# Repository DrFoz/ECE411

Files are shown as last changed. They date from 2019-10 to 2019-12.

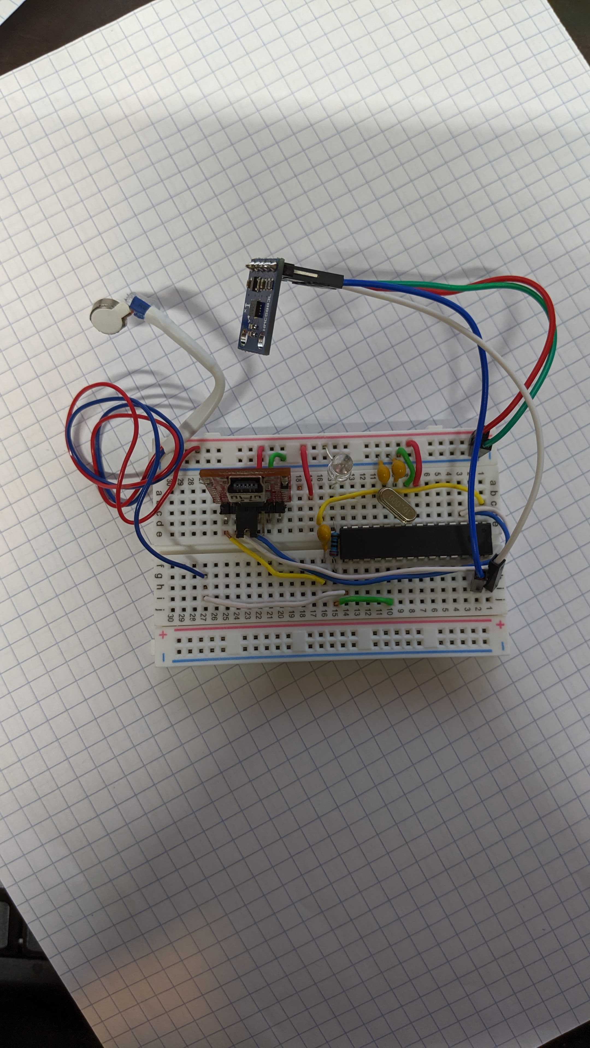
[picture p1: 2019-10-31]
IMG_20191020_224753.jpg

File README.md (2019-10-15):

# ECE411
Repository for ECE 411 practicum project documentation

Project overview

This project encompasses the hardware and software design of a haptic feedback compass
to assist an individual with landbased navigation.
Applications could include hiking, hunting, or as additional aid for the visually impaired.
Direction will be determined with the use of a digital magnometer and microprocessor. 
Mode Select and direction select will be set with the use of a momentary switch mounted to 
the case. Feedback will be generated using micro dc vibrator motor, to indicate mode and
direction selected, as well as to indicate a deviation from desired direction. During 
operation Haptic feedback intensity will be preportional to the deviation of desired 
direction of travel. Device will be powered by a lithium polymer pouch cell that is 
removable and rechargeable via external charger.

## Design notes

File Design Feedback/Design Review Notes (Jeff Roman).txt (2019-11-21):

- Board needs to have bypass capacitors on Vcc and likely on the 5V Regulator.
- Round out some of the PCB traces into a 'Knee-like' roundout.
- Via 'Fencing' or Via's close to important grounded areas.

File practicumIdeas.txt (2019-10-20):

Practicum project concepts

1. Self driving doorstop

	This design would would use infrared line tracking sensors, and user placed paths to guide a wheeled doorstop to the optimum location for door stoppage. The operation can be activated using an IR remote, or be set to auto-mode where it will secure the nearest door it can find. The actuator for the wheels will be done using a stepper motor to prevent slippage when the doorstop is in the resting state. An Atmega328P will be used with the addition of a A4988 stepper motor driver.

2. Battery Voltage tester

	This project would use a voltage sensor to test 1.5V and 9V batteries. Sensor readings would be processed using an Atmega328P microprocessor and the output(actuator) would be an oled display with the raw voltage reading and 8 led strip that would act as a bad/good gauge feedback to the user.

3.Haptic feedback compass

	This project will use a digital magnometer and an Atmega328P microprocessor to determine the direction the device is oriented. It will be worn by the user on a lanyard around there neck. Mode Select and Direction select will be set with the use of a momentary switch mounted to the case. Feedback will be generated using micro dc vibrator motor, to indicate mode and direction selected, as well as to indicate a deviation from desired direction. During operation Haptic feedback intensity will be preportional to the deviation of desired direction of travel. This can be used to assist an individual with landbased navigation. Applications could include hiking, hunting, or as additional aid for the visually impaired. 
	
We have chosen to work on the Haptic feedback compass for our practicum project.

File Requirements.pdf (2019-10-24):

# HAPTIC FEEDBACK COMPASS

## REQUIREMENTS

TYSON FOSDICK

TODD TOWNSEND

RUBEN MALDONADO

MATT SCHROEDER

Project Requirements Date: 10/15/2019

Version Number: 1.0

ECE 411

Department of Electrical and Computer Engineering

## Project Summary

This project encompasses the hardware and software design of a haptic feedback compass to assist an individual with land-based navigation. Direction will be determined with the use of a digital magnetometer and microprocessor. During operation Haptic feedback intensity will be proportional to the deviation of the end users desired direction of travel. Depending on the customer and desired application our design will accommodate multiple users creating a diverse clientele encompassing the wide range of applications.

Background
Original concept was a design for a haptic feedback dog collar to help visual impaired dogs with obstacle avoidance. This design had extreme challenges due to the unpredictable nature of the animals movement. The concept for the compass was derived from the collar project as a simplified version of the feedback device, to gain real-world tests of the components that may lead to a solution to the collar project challenges. During the product concept phase, the alternate use for the visually impaired was added to the design, as well as the concept of a web based application of the device.

## Market Analysis

The product is targeted towards hunters, hikers, and general outdoors enthusiast primarily. Alternate application for the visually impaired will be implemented after thorough real-world testing and customer feedback has been acquired, and safety and feasibility have been assessed.

There are no comparable products currently commercially available, although there are a few open source projects in the maker community that are similar in build but differ in functionality. The closest our team could find was a visual display digital compass with price ranging from ~$12-$30. Analog compass price range from ~$8-$100.

The product will be introduced at a $80 price point mainly to get a quicker market share, and get useful customer analytics for future product releases. The price will be increased with future upgraded models.

## Design Requirements

Design was created adhering to the following requirements:

Musts

Functionality

1. Acquired heading accurately reported to user
2. Operate on battery for a minimum of 4 hours

Performance

1. Give accurate feedback within a 5° plus or minus deviation
2. Low power consumption ~300mW

Economic

1. User interface equipped with user friendly options, reported from users
2. Navigation need fulfilled, reported from users
3. Priced within the market range for similar products or combination of products to equal functionality

Shoulds

Functionality

1. Run on battery for 8 hours

Performance

1. Have a rugged damage resistant enclosure
2. Be waterproof, cold resistant and heat resistant
3. Operate with extremely low power consumption ~160mW

Economic

1. Comfortable to wear, reported from users
2. Look attractive, reported from users
3. Cost no more than the cost of a commercially available digital/analog compass.

Architecture Overview:

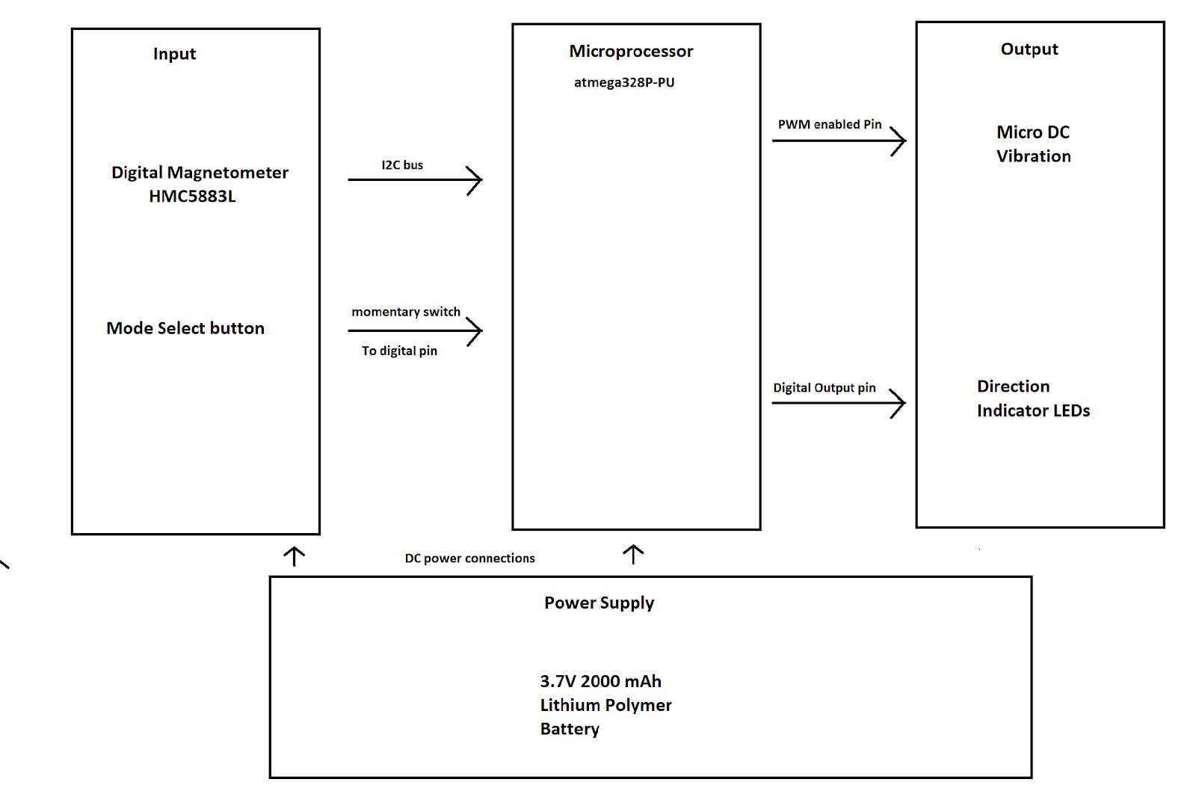
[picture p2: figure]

## Specifications:

- Processor - Atmega328P-PU with Arduino bootloader Version 3.0
- Sensor - magnetometer - P/N HMC5883L
- Actuator - Micro DC vibration motor 3v 85mA
- Power Source - 3.7v 2000mAh Lithium Polymer pouch cell
- Programming environment - Arduino IDE/Visual Studio Code
- PCB schematics - Eagle CAD
- Enclosure - Printed ABS plastic

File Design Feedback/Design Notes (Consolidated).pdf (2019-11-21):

# Design Notes (Consolidated)

## Team 6: Matthew Schroeder Todd Townsend Tyson Fosdick Ruben Maldonado

Date of review: 11/20/2019

Design reviewed by individuals from two teams: Jeff Roman
Thomas Harris

Board Layout
- Silk screen overlap throughout board.
- Silk screen is off the board in top left corner.
- Chunk of trace in DRC.
- Team name and date needs to be on board.
- Ground stitching vias are not present.
- ERC Warnings (Components that don’t need values).
- Ext. connectors and LEDs.
- Traces might need to be rounded out.
- Via ‘fencing’ or putting via’s close to important grounds may be advantageous

Schematic
- Pin 22 not grounded.
- AVCC and AREF are floating.
- User-Button not a very meaningful name.
- Labeling is done very well.
- Bypass capacitors lacking on VCC and likely 5V regulator.

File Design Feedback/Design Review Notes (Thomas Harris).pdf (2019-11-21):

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
Design notes

Board Layout
silk screen overlap throughout board
silk screen is off of the board in top left corner
chunk of trace in DRC (just a warning, wonʼt break anything)
team name and date needs to be on board
ground stitching vias are not present
you guys have a bunch of ERC warnings (components that donʼt need values, such as external connectors and LEDs, need an inherent value associated) (just a warning, wonʼt break anything)

Schematic
pin 22 is not grounded
AVCC and AREF are floating, double check that this is okay. (it should probably have a pullup or pulldown cap)
specify function of “user-button” not the most meaningful name
labeling is very well done

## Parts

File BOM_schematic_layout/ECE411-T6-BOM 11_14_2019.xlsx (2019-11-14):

Qty / Board | Qty - Total | Manufacturer Number | Manufacturer | Reference Designation | Description | SMD/Through-Hole | Price - Component | Price/Board | Price - Total | External Link:
2 | 8 | 10129379-905001BLF | Amphenol FCI (https://www.mouser.com/manufacturer/fci/) | JP1, JP2 | Header | Through-Hole | $0.26 | $0.52 | $2.08
2 | 8 | 503562 | Adafruit Industries LLC (https://www.digikey.com/en/supplier-centers/a/adafruit) | BATT | 3.7V Lipo Battery | N/A | $9.95 | $19.90 | $79.60 | https://www.adafruit.com/product/258
2 | 8 | S2B-PH-K-S(LF)(SN) | JST Sales America Inc. (https://www.digikey.com/en/supplier-centers/j/jst) | 3.7V-LIPO-1, 3.7V-LIPO-2 | JST-PH2 Connectors | Through-Hole | $0.17 | $0.34 | $1.36 | https://www.newegg.com/p/2A7-00D0-00060?item=9SIAAZM4G87031&nm_mc=knc-googlemkp-pc&gclsrc=aw.ds
1 | 4 | GY-273 HMC5883L | Honeywell (HMC5883L) | GY-273 HMC5883L | Magnetic Sensor | Through-Hole | $4.88 | $4.88 | $19.52
7 | 28 | RCS08050000Z0EA | Vishay Dale (https://www.digikey.com/en/supplier-centers/v/vishay-dale) | R4-10 | 0 Ohm Resistor | SMD | $0.17 | $1.19 | $4.76
1 | 4 | CRCW08051K50FKEAC | Vishay Dale (https://www.digikey.com/en/supplier-centers/v/vishay-dale) | R13 | 1.5 kOhm Resistor | SMD | $0.10 | $0.10 | $0.40
1 | 4 | CRCW08055K00FKTA | Vishay Dale (https://www.digikey.com/en/supplier-centers/v/vishay-dale) | R2 | 5 kOhm Resistor | SMD | $0.15 | $0.15 | $0.60
3 | 12 | CRCW0805100KJNEAC | Vishay Dale (https://www.digikey.com/en/supplier-centers/v/vishay-dale) | R1, R11, R12 | 100 kOhm Resistor | SMD | $0.10 | $0.30 | $1.20
1 | 4 | CRCW08051M00FKEAC | Vishay Dale (https://www.digikey.com/en/supplier-centers/v/vishay-dale) | R3 | 1 MOhm Resistor | SMD | $0.10 | $0.10 | $0.40
1 | 4 | C0805C222K2RECAUTO | KEMET (https://www.mouser.in/manufacturer/kemet-electronics/) | C1 | 2200pF Capacitor | SMD | $0.27 | $0.27 | $1.08
1 | 4 | TMCP1D224MTRF | Vishay / Sprague (https://www.mouser.in/manufacturer/sprague/) | C5 | 0.22uF Capacitor | SMD | $0.46 | $0.46 | $1.84
2 | 8 | 500R15N220JV4T | Johanson Dielectrics (https://www.mouser.in/manufacturer/johanson-dielectrics/) | C2, C3 | 22pF Capacitor | SMD | $0.15 | $0.30 | $1.20
1 | 4 | C0805C101J5HACAUTO | KEMET (https://www.mouser.in/manufacturer/kemet-electronics/) | C4 | 100pF Capacitor | SMD | $0.16 | $0.16 | $0.64
4 | 16 | PBHV8115TLHR | Nexperia (https://www.mouser.in/manufacturer/nexperia/) | Q1-4 | NPN Transistor | SMD | $0.39 | $1.56 | $6.24
1 | 4 | L101011MS02Q | C&K (https://www.mouser.in/manufacturer/ck-switches/) | SPST-SLIDE-SWITCH | Slideswitch | Through-Hole | $1.97 | $1.97 | $7.88
1 | 4 | TC33X-2-504G | Bourns (https://www.mouser.in/manufacturer/bourns/) | VR1 | 500 kOhm Potentiometer | SMD | $0.26 | $0.26 | $1.04
1 | 4 | ECS-160-8-30Q-VY-TR | ECS (https://www.mouser.in/manufacturer/ecs/) | Y1 | 16 MHz Oscillator | SMD | $0.72 | $0.72 | $2.88
4 | 16 | HLMP-6820 | Broadcom / Avago (https://www.mouser.in/manufacturer/broadcom/) | LED-N, LED-S, LED-E, LED-W | 5V 3.5mA Green LEDs | Through-Hole | $0.90 | $3.60 | $14.40
2 | 8 | BAS21GWX | Nexperia (https://www.mouser.in/manufacturer/nexperia/) | D1, D2 | Diode | SMD | $0.17 | $0.34 | $1.36
1 | 4 | MMSZ4684T1G | ON Semiconductor (https://www.mouser.in/manufacturer/on-semiconductor/) | Z1 | Zener Diode | SMD | $0.20 | $0.20 | $0.80
1 | 4 | SN74LVC1G14DBVR | Texas Instruments (https://www.mouser.in/manufacturer/texas-instruments/) | IC1 | Shottky Inverter | SMD | $0.33 | $0.33 | $1.32
1 | 4 | ATMEGA328P-PU | Microchip Technology / Atmel (https://www.mouser.in/manufacturer/atmel/) | U1 | Microprocessor | Through-Hole | $2.14 | $2.14 | $8.56
1 | 4 | 1241.1072 | Schurter (https://www.mouser.com/manufacturer/schurter/) | BUTTON | Flush OFF - (ON) Button | Through-Hole | $3.01 | $3.01 | $12.04
 |  |  |  |  |  |  | Total: | $42.80 | $171.20
 |  |  |  |  | SMD/Through-Hole Percentages
 |  |  |  |  | Through-Hole Types: | 7
 |  |  |  |  | Through-Hole Components: | 12
 |  |  |  |  | SMD Types: | 15
 |  |  |  |  | SMD Components: | 28
 |  |  |  |  | SMD Percentage: | 70

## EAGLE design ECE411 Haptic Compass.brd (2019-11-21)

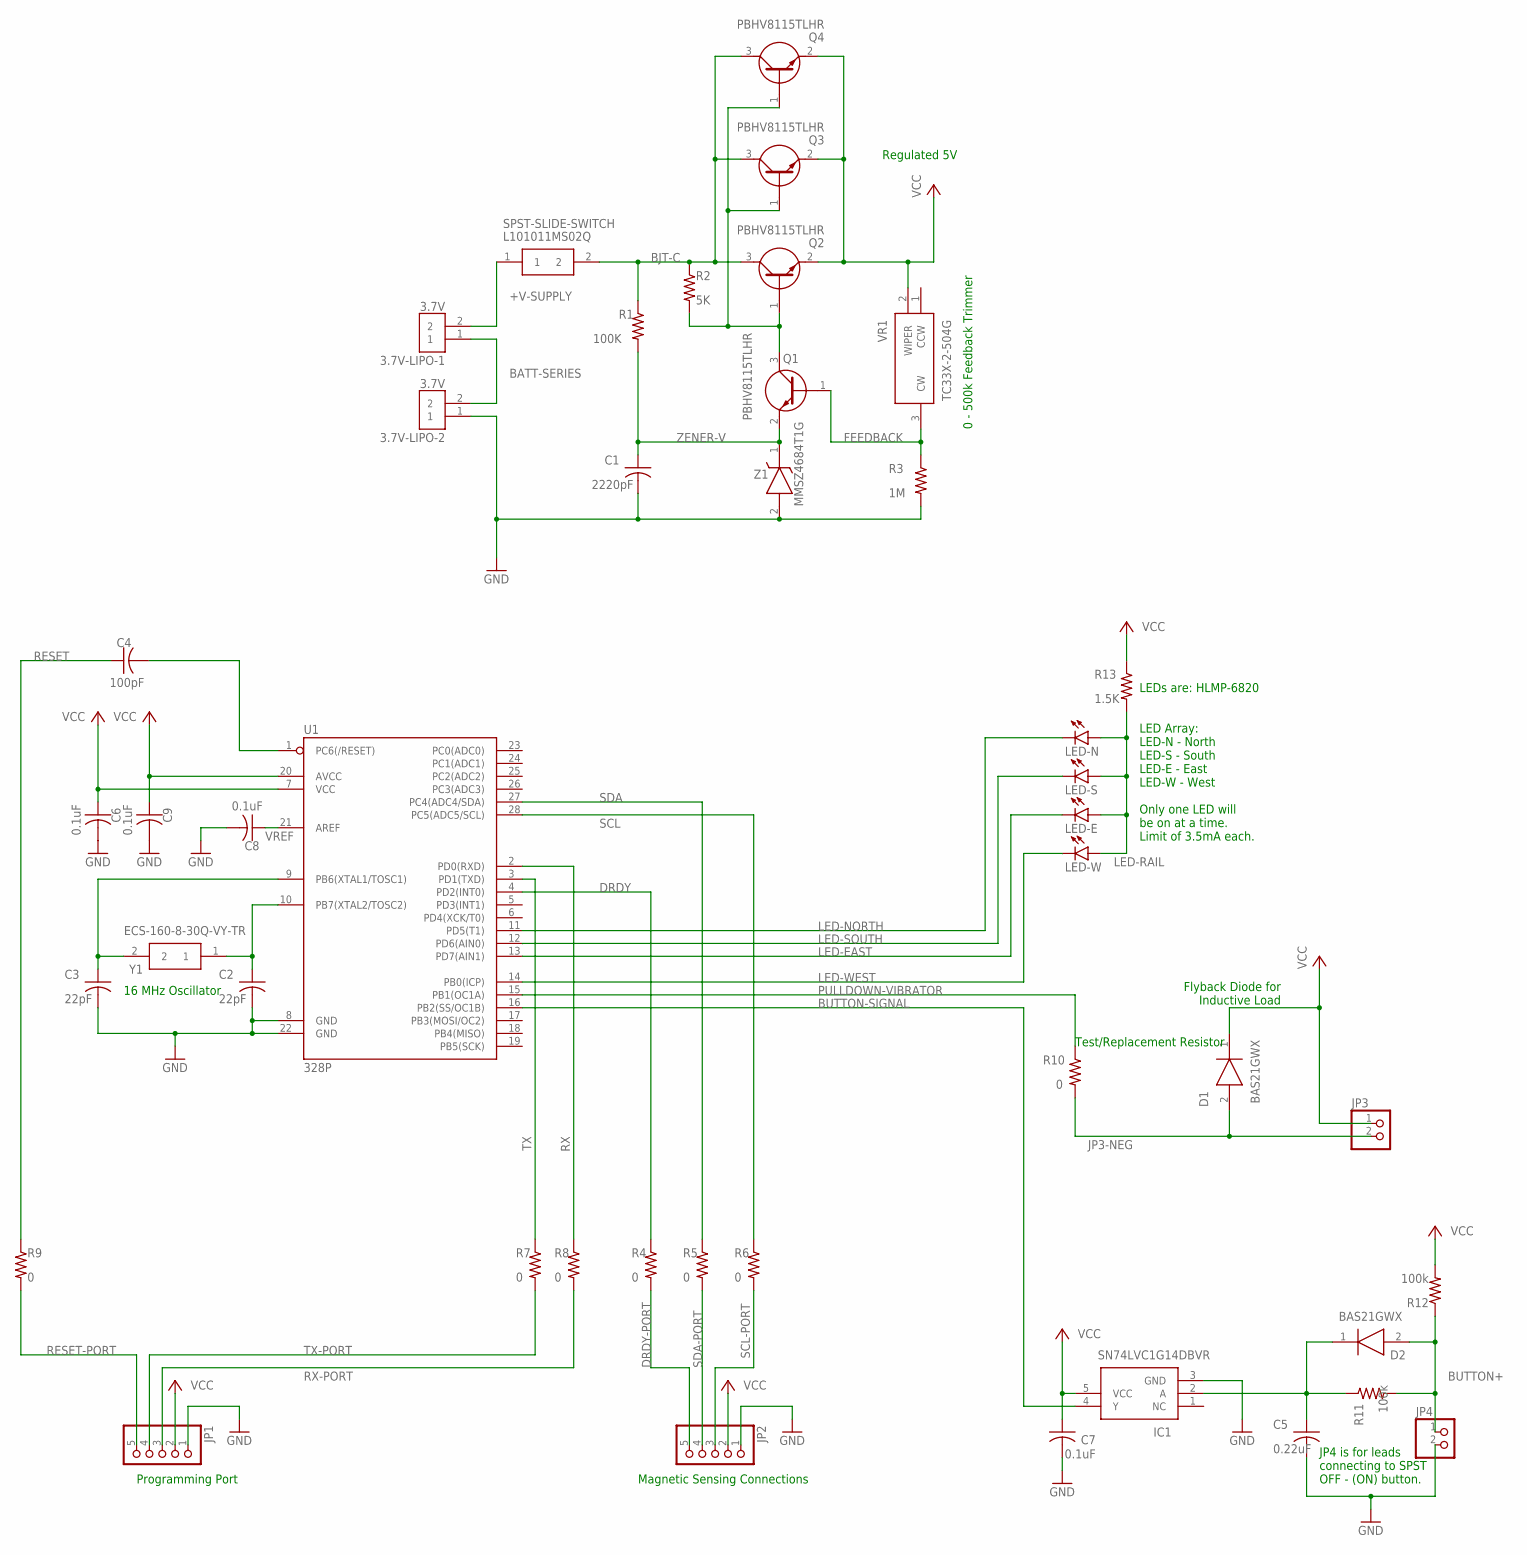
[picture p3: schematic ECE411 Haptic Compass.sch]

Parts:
3.7V-LIPO-1, 3.7V-LIPO-2: 3.7V; JST_S2B-PH-K-S(LF)(SN)
C1: 2220pF; C0805
C2, C3: 22pF; C0805
C4: 100pF; C0805
C5: 0.22uF; C0805
C6, C7, C8, C9: 0.1uF; C0805
D1, D2: BAS21GWX; SOD3616X130N
IC1: SN74LVC1G14DBVR; SOT95P280X145-5N
JP1, JP2: PINHD-1X5; 1X05
JP3, JP4: PINHD-1X2; 1X02
LED-E: LED5MM
LED-N: LED5MM
LED-S: LED5MM
LED-W: LED5MM
Q1, Q2, Q3, Q4: PBHV8115TLHR; SOT95P230X110-3N
R1: 100K; R0805
R2: 5K; R0805
R3: 1M; R0805
R4, R5, R6, R7, R8, R9, R10: 0; R0805
R11, R12: 100k; R0805
R13: 1.5K; R0805
SPST-SLIDE-SWITCH: L101011MS02Q; CKC5106-ND
U1: 328P; DIP28
VR1: TC33X-2-504G; TC33X-2_1
Y1: ECS-160-8-30Q-VY-TR; ECS80830QVSTR
Z1: MMSZ4684T1G; SOD3716X135N

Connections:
+V-SUPPLY: 3.7V-LIPO-1.2, SPST-SLIDE-SWITCH.1
BATT-SERIES: 3.7V-LIPO-1.1, 3.7V-LIPO-2.2
BJT-C: Q2.3 (C), Q3.3 (C), Q4.3 (C), R1.1, R2.1, SPST-SLIDE-SWITCH.2
BUTTON+: D2.2 (A), JP4.1, R11.2, R12.1
BUTTON-SIGNAL: IC1.4 (Y), U1.16 (PB2(SS/OC1B))
DRDY: R4.1, U1.4 (PD2(INT0))
DRDY-PORT: JP2.5, R4.2
FEEDBACK: Q1.1 (B), R3.1, VR1.3 (CW)
GND: 3.7V-LIPO-2.1, C1.2, C2.2, C3.2, C5.2, C6.2, C7.2, C8.2, C9.2, IC1.3 (GND), JP1.1, JP2.1, JP4.2, R3.2, U1.8 (GND), U1.22 (GND), Z1.2 (A)
JP3-NEG: D1.2 (A), JP3.2, R10.2
LED-EAST: LED-E.K (C), U1.13 (PD7(AIN1))
LED-NORTH: LED-N.K (C), U1.11 (PD5(T1))
LED-RAIL: LED-E.A, LED-N.A, LED-S.A, LED-W.A, R13.2
LED-SOUTH: LED-S.K (C), U1.12 (PD6(AIN0))
LED-WEST: LED-W.K (C), U1.14 (PB0(ICP))
unnamed: C4.2, U1.1 (PC6(/RESET))
unnamed: C5.1, D2.1 (K), IC1.2 (A), R11.1
unnamed: C2.1, U1.10 (PB7(XTAL2/TOSC2)), Y1.1
unnamed: C3.1, U1.9 (PB6(XTAL1/TOSC1)), Y1.2
unnamed: Q1.3 (C), Q2.1 (B), Q3.1 (B), Q4.1 (B), R2.2
PULLDOWN-VIBRATOR: R10.1, U1.15 (PB1(OC1A))
RESET: C4.1, R9.1
RESET-PORT: JP1.5, R9.2
RX: R8.1, U1.2 (PD0(RXD))
RX-PORT: JP1.3, R8.2
SCL: R6.1, U1.28 (PC5(ADC5/SCL))
SCL-PORT: JP2.3, R6.2
SDA: R5.1, U1.27 (PC4(ADC4/SDA))
SDA-PORT: JP2.4, R5.2
TX: R7.1, U1.3 (PD1(TXD))
TX-PORT: JP1.4, R7.2
VCC: C6.1, C7.1, C9.1, D1.1 (K), IC1.5 (VCC), JP1.2, JP2.2, JP3.1, Q2.2 (E), Q3.2 (E), Q4.2 (E), R12.2, R13.1, U1.7 (VCC), U1.20 (AVCC), VR1.2 (WIPER)
VREF: C8.1, U1.21 (AREF)
ZENER-V: C1.1, Q1.2 (E), R1.2, Z1.1 (K)

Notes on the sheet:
16 MHz Oscillator
Regulated 5V
0 - 500k Feedback Trimmer
Programming Port
Magnetic Sensing Connections
Flyback Diode for Inductive Load
Test/Replacement Resistor
JP4 is for leads connecting to SPST OFF - (ON) button.
LEDs are: HLMP-6820 LED Array: LED-N - North LED-S - South LED-E - East LED-W - West Only one LED will be on at a time. Limit of 3.5mA each.

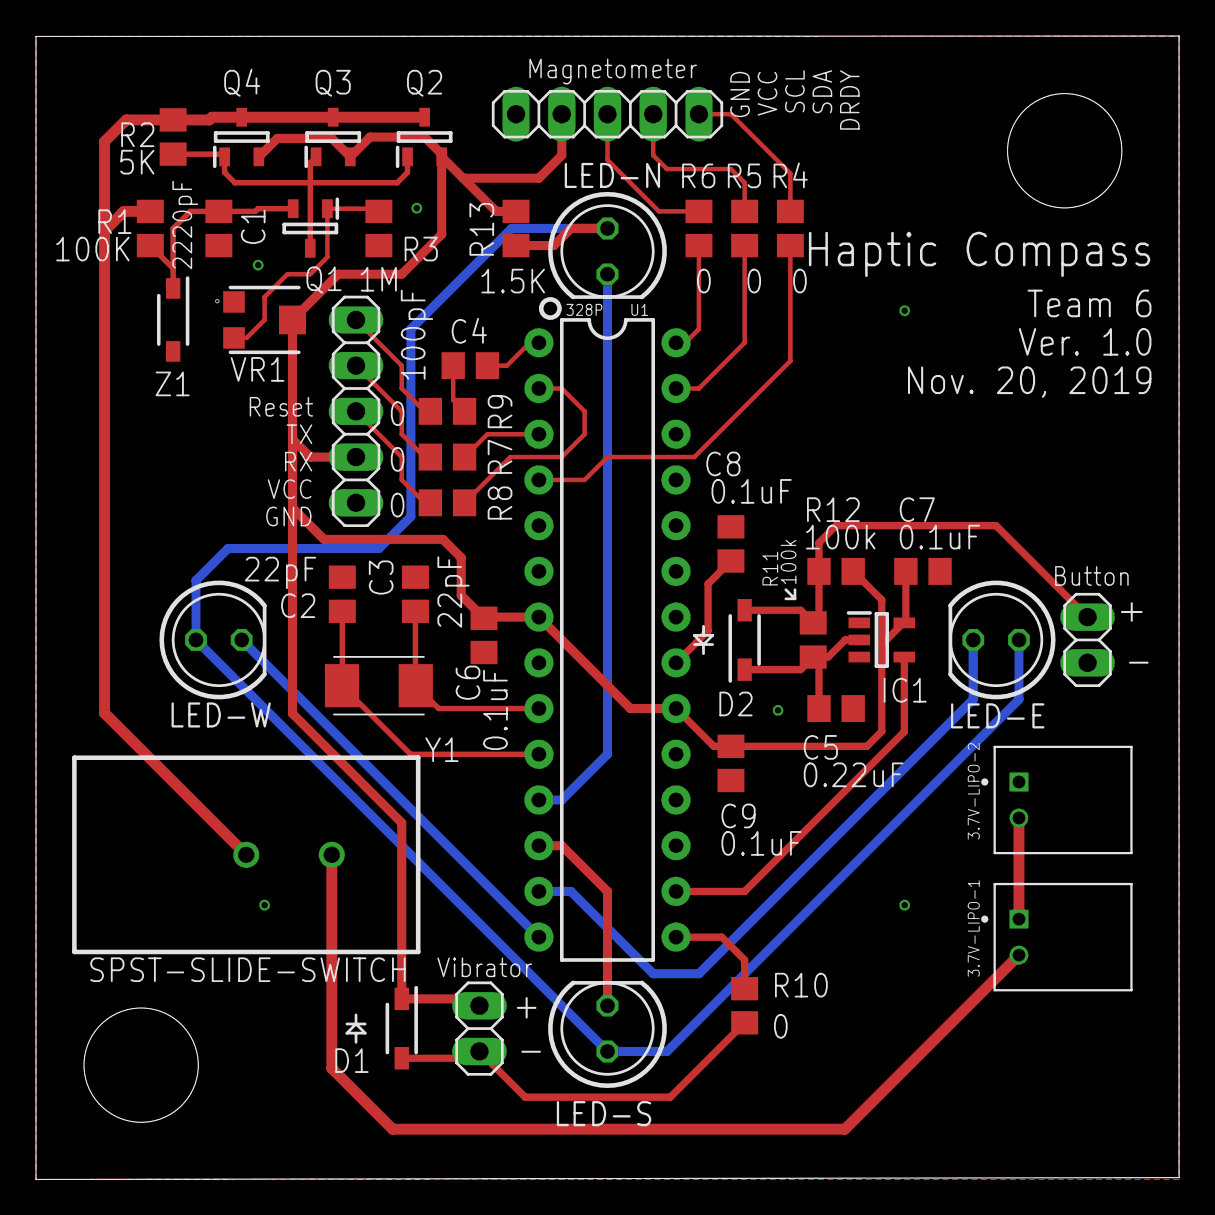
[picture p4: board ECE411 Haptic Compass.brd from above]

Board: 2 copper layers, 63.5 x 63.5 mm, 44 parts (0 on the bottom side), 34 nets.

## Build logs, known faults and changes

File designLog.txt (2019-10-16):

10-15-2019 TF-Estimated physical design specifications and decided to start layout to fit inside a 7 cm diameter encloser with 3 cm depth. Current battery occupies the most space, final design should have a lower profile battery. Link below to possible cell.
https://www.alliedelec.com/product/adafruit-industries/328/70928240/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

10-15-2019 TF-Mounted components to breadboard, built basic 5v regulated powersupply using LM7805, final design will utilize 3.3v regulator due to battery voltage contraints.

10-15-2019 TF-Finished wiring of breadboard, added 16MHz quartz osillator, and connection points for FTDI adapter. Attempted to upload blink sketch but was unsucessful, possible due to not have recommended capacitor type/value for osillator circuit.

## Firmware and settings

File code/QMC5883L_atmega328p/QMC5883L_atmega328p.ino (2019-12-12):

#include <QMC5883L.h>
#include <Wire.h>

int northLED = 5;
int southLED = 6;
int eastLED = 7;
int westLED = 8;
boolean currentButton = LOW;
int modeSelect = 2;
volatile byte directionSet = 0; //variable to inticate direction selected


int p = 0;
int motorPinLeft = 9;
int motorPinRight = 10;
QMC5883L compass;

void setup()
{
  Serial.begin(9600);
	Wire.begin();
  attachInterrupt(digitalPinToInterrupt(modeSelect), changeDirection, FALLING);
	compass.init();
	compass.setSamplingRate(50);
  pinMode(modeSelect, INPUT);
  
  pinMode(motorPinLeft, OUTPUT);
  pinMode(motorPinRight, OUTPUT);
  
  pinMode(northLED, OUTPUT);
  pinMode(southLED, OUTPUT);
  pinMode(eastLED, OUTPUT);
  pinMode(westLED, OUTPUT);
  
	Serial.begin(9600);
	Serial.println("QMC5883L Compass Demo");
	Serial.println("Turn compass in all directions to calibrate....");

 
}


void loop()
{
 Serial.println("Direction set is  ");
 Serial.println(directionSet);
	int r;
  int16_t x,y,z,t;
  r = compass.readRaw(&x,&y,&z,&t);

 	int heading = compass.readHeading();
  p = heading; //Reassignment here just incase I needed to do mathmatical manipulations to value
  Serial.println("direction is");
  Serial.println(p);
  Serial.println("Mode select ");
  Serial.println(directionSet);
  if(directionSet == 0){
    digitalWrite(northLED, LOW);
    digitalWrite(eastLED, HIGH);
    digitalWrite(southLED, HIGH);
    digitalWrite(westLED, HIGH);
  }
 if(directionSet == 1){
    digitalWrite(northLED, HIGH);
    digitalWrite(eastLED, LOW);
    digitalWrite(southLED, HIGH);
    digitalWrite(westLED, HIGH);
  }
   if(directionSet == 2){
    digitalWrite(northLED, HIGH);
    digitalWrite(eastLED, HIGH);
    digitalWrite(southLED, LOW);
    digitalWrite(westLED, HIGH);
  }
   if(directionSet == 3){
    digitalWrite(northLED, HIGH);
    digitalWrite(eastLED, HIGH);
    digitalWrite(southLED, HIGH);
    digitalWrite(westLED, LOW);
  }
  //Logic dependend on direction selected  
  switch (directionSet) {
    
    //Mode selected for Northward travel///////////////////////////////////////////////////////////////////////////////////////
    case 0:
    
    if((p > 355)||(p < 5)){
    Serial.println("Heading North");

    digitalWrite(motorPinLeft, HIGH);
    digitalWrite(motorPinRight, HIGH);
    
    
    //LED feedback for debugging only
    
//    /*digitalWrite(northLED, LOW);
//    digitalWrite(southLED, HIGH);
//    digitalWrite(eastLED, HIGH);
//    digitalWrite(westLED, HIGH);*/
  }
  
  if((p > 10) && (p < 90)){
    Serial.println("Slightly right");

    analogWrite(motorPinLeft, 0);
    analogWrite(motorPinRight, 128);
   
    
    //LED feedback for debugging only
//    digitalWrite(northLED, HIGH);
//    digitalWrite(southLED, HIGH);
//    digitalWrite(eastLED, LOW);
//    digitalWrite(westLED, HIGH);
    
  }  

  if((p > 95) &&(p < 179)){
    Serial.println("Extremely Right");

    analogWrite(motorPinLeft, 0);
    analogWrite(motorPinRight, 255);
    
    //LED feedback for debugging only
//    digitalWrite(northLED, HIGH);
//    digitalWrite(southLED, LOW);
//    digitalWrite(eastLED, HIGH);
//    digitalWrite(westLED, HIGH);
    
  } 

  if((p > 180) && (p < 269)){
    Serial.println("Extremely Left");

    analogWrite(motorPinLeft, 255);
    analogWrite(motorPinRight, 0);
    
    //LED feedback for debugging only
//    digitalWrite(northLED, HIGH);
//    digitalWrite(southLED, LOW);
//    digitalWrite(eastLED, HIGH);
//    digitalWrite(westLED, HIGH);
    
  } 

   if((p > 270) && (p < 352)){
    Serial.println("Slightly Left");
   
    analogWrite(motorPinLeft, 128);
    analogWrite(motorPinRight, 0);
    
    //LED feedback for debugging only
//    digitalWrite(northLED, HIGH);
//    digitalWrite(southLED, HIGH);
//    digitalWrite(eastLED, HIGH);
//    digitalWrite(westLED, LOW);
    
  } 
  delay(200);
  break;

// Mode selected for Eastward Travel///////////////////////////////////////////////////////////////////////////////////////////
  case 1:
   if((p > 85) && (p < 95)){
    Serial.println("Heading East");
    
    digitalWrite(motorPinLeft, LOW);
    digitalWrite(motorPinRight, LOW);
    
    //LED feedback for debugging only
    
//    digitalWrite(northLED, HIGH);
//    digitalWrite(southLED, LOW);
//    digitalWrite(eastLED, HIGH);
//    digitalWrite(westLED, HIGH);
  }
  
  if((p > 96) && (p < 179)){
    Serial.println("Slightly Right");
    
    analogWrite(motorPinLeft, 0);
    analogWrite(motorPinRight, 128);
    
    //LED feedback for debugging only
//    digitalWrite(northLED, HIGH);
//    digitalWrite(southLED, HIGH);
//    digitalWrite(eastLED, HIGH);
//    digitalWrite(westLED, LOW);
    
  }  

  if((p > 180) &&(p < 269)){
    Serial.println("Extremely Right");
    
   analogWrite(motorPinLeft, 0);
    analogWrite(motorPinRight, 255);
    
    //LED feedback for debugging only
//    digitalWrite(northLED, HIGH);
//    digitalWrite(southLED, LOW);
//    digitalWrite(eastLED, HIGH);
//    digitalWrite(westLED, HIGH);
    
  } 

  if((p > 181) && (p < 270)){
    Serial.println("Extremely Left");
    
    analogWrite(motorPinLeft, 255);
    analogWrite(motorPinRight, 0);
    
    //LED feedback for debugging only
//    digitalWrite(northLED, HIGH);
//    digitalWrite(southLED, LOW);
//    digitalWrite(eastLED, HIGH);
//    digitalWrite(westLED, HIGH);
    
  } 

   if((p > 270) && (p < 360)){
    Serial.println("Slightly Left");
    
    analogWrite(motorPinLeft, 128);
    analogWrite(motorPinRight, 0);
    
    //LED feedback for debugging only
//    digitalWrite(northLED, HIGH);
//    digitalWrite(southLED, HIGH);
//    digitalWrite(eastLED, LOW);
//    digitalWrite(westLED, HIGH);
    
  } 
  delay(200);
  break;

//Mode selected for southward direction/////////////////////////////////////////////////////////////////
  case 2:
 if((p > 175) && (p < 185)){
    Serial.println("Heading South");
    
   digitalWrite(motorPinLeft, LOW);
    digitalWrite(motorPinRight, LOW);
    
    //LED feedback for debugging only
    
//    digitalWrite(northLED, HIGH);
//    digitalWrite(southLED, LOW);
//    digitalWrite(eastLED, HIGH);
//    digitalWrite(westLED, HIGH);
  }
  
  if((p > 186) && (p < 269)){
    Serial.println("Slightly Right");
    
    analogWrite(motorPinLeft, 0);
    analogWrite(motorPinRight, 128);
    
    //LED feedback for debugging only
//    digitalWrite(northLED, HIGH);
//    digitalWrite(southLED, HIGH);
//    digitalWrite(eastLED, HIGH);
//    digitalWrite(westLED, LOW);
    
  }  

  if((p > 271) &&(p < 360)){
    Serial.println("Extremely Right");
    
   analogWrite(motorPinLeft, 0);
    analogWrite(motorPinRight, 255);
    
    //LED feedback for debugging only
//    digitalWrite(northLED, HIGH);
//    digitalWrite(southLED, LOW);
//    digitalWrite(eastLED, HIGH);
//    digitalWrite(westLED, HIGH);
    
  } 

  if((p > 1) && (p < 90)){
    Serial.println("Extremely Left");
    
    analogWrite(motorPinLeft, 255);
    analogWrite(motorPinRight, 0);
    
    //LED feedback for debugging only
//    digitalWrite(northLED, HIGH);
//    digitalWrite(southLED, LOW);
//    digitalWrite(eastLED, HIGH);
//    digitalWrite(westLED, HIGH);
    
  } 

   if((p > 91) && (p < 174)){
    Serial.println("Slightly Left");
    
    analogWrite(motorPinLeft, 128);
    analogWrite(motorPinRight, 0);
    
    //LED feedback for debugging only
//    digitalWrite(northLED, HIGH);
//    digitalWrite(southLED, HIGH);
//    digitalWrite(eastLED, LOW);
//    digitalWrite(westLED, HIGH);
    
  } 
  delay(200);
  break;

//Mode selected for Westward travel////////////////////////////////////////////////////////////////////////////////
  case 3:
   if((p > 265)&&(p < 275)){
    Serial.println("Heading West");
    
    digitalWrite(motorPinLeft, LOW);
    digitalWrite(motorPinRight, LOW);
    
    //LED feedback for debugging only
    
//    digitalWrite(northLED, HIGH);
//    digitalWrite(southLED, HIGH);
//    digitalWrite(eastLED, HIGH);
//    digitalWrite(westLED, LOW);
  }
  
  if((p > 276) && (p < 360)){
    Serial.println("Slightly Right");
    
   analogWrite(motorPinLeft, 0);
    analogWrite(motorPinRight, 128);
    
    //LED feedback for debugging only
//    digitalWrite(northLED, LOW);
//    digitalWrite(southLED, HIGH);
//    digitalWrite(eastLED, HIGH);
//    digitalWrite(westLED, HIGH);
    
  }  

  if((p > 1) &&(p < 89)){
    Serial.println("Extremely Right");
    
    analogWrite(motorPinLeft, 0);
    analogWrite(motorPinRight, 255);
    
    //LED feedback for debugging only
//    digitalWrite(northLED, HIGH);
//    digitalWrite(southLED, HIGH);
//    digitalWrite(eastLED, LOW);
//    digitalWrite(westLED, HIGH);
    
  } 

  if((p > 90) && (p < 179)){
    Serial.println("Extremely Left");
    
    analogWrite(motorPinLeft, 128);
    analogWrite(motorPinRight, 0);
    
    //LED feedback for debugging only
//    digitalWrite(northLED, HIGH);
//    digitalWrite(southLED, HIGH);
//    digitalWrite(eastLED, LOW);
//    digitalWrite(westLED, HIGH);
    
  } 

   if((p > 180) && (p < 360)){
    Serial.println("Slightly Left");
    
    analogWrite(motorPinLeft, 128);
    analogWrite(motorPinRight, 0);
    
    //LED feedback for debugging only
//    digitalWrite(northLED, HIGH);
//    digitalWrite(southLED, LOW);
//    digitalWrite(eastLED, HIGH);
//    digitalWrite(westLED, HIGH);
    
  } 
  break;
	}
 delay(200);
}


void changeDirection() {
  
  Serial.println("selecting new mode");
  static unsigned long last_interrupt_time = 0;
  unsigned long interrupt_time = millis();
  if(interrupt_time - last_interrupt_time > 800)
  {
  if(directionSet < 3)
        directionSet = directionSet +1;
        else
        directionSet = 0;
  }     
  
  //detachInterrupt(digitalPinToInterrupt(modeSelect));
  //attachInterrupt(digitalPinToInterrupt(modeSelect), changeDirection, CHANGE);
  
}

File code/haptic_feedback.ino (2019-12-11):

/* Start of Code */

#include <Wire.h>
#include <HMC5883L.h>

//heptic motor
int motorPin = 9;

//leds to indicate direction
int LED_n = 5;
int LED_e = 7;
int LED_s = 6;
int LED_w = 8;

int req_direction = 0;
  
int speed = 255;
int prev_speed = 255;

//change direction button
int buttonPin = 2;

int curr_direction = 1;
int buttonState = 0;  
int lastButtonState = 0;  

HMC5883L compass;

void setup(){
  Serial.begin(9600);
  pinMode(motorPin, OUTPUT);
  pinMode(LED_n, OUTPUT);
  pinMode(LED_e, OUTPUT);
  pinMode(LED_s, OUTPUT);
  pinMode(LED_w, OUTPUT);
  pinMode(buttonPin, INPUT);
  
  analogWrite(motorPin, 255);
  Wire.begin();
  
  digitalWrite(LED_n, LOW);
  digitalWrite(LED_e, HIGH);
  digitalWrite(LED_s, HIGH);
  digitalWrite(LED_w, HIGH);
  
  // Set measurement range
  compass.setRange(HMC5883L_RANGE_1_3GA);
  
  // Set measurement mode
  compass.setMeasurementMode(HMC5883L_CONTINOUS);
  
  // Set data rate
  compass.setDataRate(HMC5883L_DATARATE_30HZ);
  
  // Set number of samples averaged
  compass.setSamples(HMC5883L_SAMPLES_8);
  
  // Set calibration offset. See HMC5883L_calibration.ino
  compass.setOffset(82, -290);
}

void loop() {
  handle_button();
}

void handle_button() {
  //int req_direction = 0;
  
  // read the pushbutton input pin:
  buttonState = digitalRead(buttonPin);

  // compare the buttonState to its previous state
  if (buttonState != lastButtonState) {
    // if the state has changed, increment the counter
    if (buttonState == HIGH) {
      
      //1 = N | 2 = E | 3 = S | 4 = W
      curr_direction++;
      
      Serial.print("current direction : ");
      Serial.println(curr_direction);
    }
    
    // Delay a little bit to avoid bouncing
    delay(50);
  }
  
  // save the current state as the last state, for next time through the loop
  lastButtonState = buttonState;
  float heading = get_direction();
  
  if (curr_direction == 1) {
    digitalWrite(LED_n, LOW);
    digitalWrite(LED_e, HIGH);
    digitalWrite(LED_s, HIGH);
    digitalWrite(LED_w, HIGH);
    req_direction = 0;
  } else if (curr_direction == 2) {
    digitalWrite(LED_n, HIGH);
    digitalWrite(LED_e, LOW);
    digitalWrite(LED_s, HIGH);
    digitalWrite(LED_w, HIGH);
    req_direction = 90;
  } else if (curr_direction == 3) {
    digitalWrite(LED_n, HIGH);
    digitalWrite(LED_e, HIGH);
    digitalWrite(LED_s, LOW);
    digitalWrite(LED_w, HIGH);
    req_direction = 180;
  } else if (curr_direction == 4) {
    digitalWrite(LED_n, HIGH);
    digitalWrite(LED_e, HIGH);
    digitalWrite(LED_s, HIGH);
    digitalWrite(LED_w, LOW);
    curr_direction  = 0;
    req_direction   = 270;
  }
  //need to handle if N and req_direction minus 5 is -5 and it needs to be 355
  if (heading > (req_direction - 5) && heading < (req_direction + 5)) {
    speed = 255;
    Serial.println("(90 - 5) Heading ");  
    Serial.println(heading);  
    Serial.println("(90 - 5) req_direction ");  
    Serial.println(req_direction);  
  } else if (heading < (req_direction - 5) && heading > (req_direction - (req_direction / 2))) {
    speed = 0;
    Serial.println("low Heading ");  
    Serial.println(heading);  
    Serial.println("low req_direction ");  
    Serial.println(req_direction);  
  }
  
  Serial.println("Heading ");  
  Serial.println(heading);  
  Serial.println("prev_speed ");  
  Serial.println(prev_speed);  
  Serial.println("speed ");  
  Serial.println(speed);  

  if (prev_speed != speed){
    if (speed >= 0 && speed <= 255) {
      analogWrite(motorPin, speed);
      delay(1000);
    }
  }
  prev_speed = speed;
}

float get_direction() {
  Vector norm = compass.readNormalize();
  
  // Calculate heading
  float heading = atan2(norm.YAxis, norm.XAxis);
  
  // Set declination angle on your location and fix heading
  // You can find your declination on: http://magnetic-declination.com/
  // (+) Positive or (-) for negative
  // For Montreal,QC declination angle is -14'35W (negative)
  // portland +15 2'
  // Formula: (deg + (min / 60.0)) / (180 / M_PI);
  float declinationAngle = (15.0 + (2.0 / 60.0)) / (180 / M_PI);
  //float declinationAngle = (-15.0-(2.0/60.0)) / (180 / M_PI);;
  //heading -= declinationAngle;
  //heading += 0.26;
  
  // Correct for heading < 0deg and heading > 360deg
  if (heading < 0)
    heading += 2 * PI;
  
  
  if (heading > 2 * PI)
    heading -= 2 * PI;
  
  // Convert to degrees
  float headingDegrees = heading * (180/M_PI); 
  
  //Serial.println("BEFotr ");
  //Serial.println(headingDegrees);
  
  delay(100);
  return headingDegrees;
}

/* End of Code */

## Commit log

2019-10-15 Created BOM, Created Eagle file, modified design log
    Created BOM and populated components used to date, created empty eagle project to establish path, updated design log
    [BOM.xlsx]
2019-10-21 Create TF_failedattempt.sch
    I clearly need to get experience in eagle
    [TF_failedattempt.sch]
2019-10-21 Create HMC588L_atmega328p_motortest.ino
    Simple program to test motor functionality
2019-10-23 Update QMC5883L_atmega328p.ino
    Added code to test motor and magnetometer accuracy
2019-10-24 Update QMC5883L_atmega328p.ino
    shortened delay for testing
    [QMC5883L_atmega328p.ino]
2019-10-24 Haptic Compass Schematic
    Creation of Power Supply and implementation of libraries and the Magnetic Sensing module.
    [ECE411 Haptic Compass.sch]
2019-10-30 Added Reworked Power Supply for 5V
    [ECE411 Haptic Compass.sch]
2019-10-31 Added all modules and I/O
    Note that the Magnetic Sensing Module is there as a placeholder. The I/O pins are at the bottom for the actual device in creation.
    [ECE411 Haptic Compass.sch]
2019-10-31 Minor Fixes (ERC)
    Fixed junction errors and Vcc connection errors.
    [ECE411 Haptic Compass.sch]
2019-10-31 images folder created
    Created images folder uploaded prototype image
2019-10-31 added prototype image
2019-11-07 Increased PCB Fabrication to 12 day turnaround
    Final update
2019-11-14 Completed Schematic
    Board layout will be completed next.
2019-11-14 BOM and Haptic Compass Schematic Update
    Included all components and revamped connector for batteries for an in-stock component.
    [BOM.xlsx, ECE411 Haptic Compass RoughDraft.sch, ECE411 Haptic Compass.csv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]
2019-11-14 Renaming for T6
    [hw5_ece411_T6.xlsx]
2019-11-14 Update ECE411-T6-BOM 11_14_2019.xlsx
    [ECE411-T6-BOM 11_14_2019.xlsx]
2019-11-14 Created Board Layout for Haptic Compass
    Ground planes are left to be created. More will be done to it as revisions this week go through.
    [ECE411 Haptic Compass RoughDraft.brd, ECE411 Haptic Compass.brd, ECE411 Haptic Compass.sch]
2019-11-16 Layout Finish - Ground Plane Added
    [ECE411 Haptic Compass.brd]
2019-11-19 Placement of switch on top
    [ECE411 Haptic Compass.brd]
2019-11-20 Included 1uF Capacitor next to Vcc for the uPC
    [ECE411 Haptic Compass.brd, ECE411 Haptic Compass.sch]
2019-11-21 Board Final
    Added AVCC, AGND, and VCC bypass capacitors and connected AGND and GND.
    [ECE411 Haptic Compass.brd, ECE411 Haptic Compass.sch]
2019-11-21 Feedback Notes & Final Board
    [ECE411 Haptic Compass.brd, ECE411 Haptic Compass.sch]

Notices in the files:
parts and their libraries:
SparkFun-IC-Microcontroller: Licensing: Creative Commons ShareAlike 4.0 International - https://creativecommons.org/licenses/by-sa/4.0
